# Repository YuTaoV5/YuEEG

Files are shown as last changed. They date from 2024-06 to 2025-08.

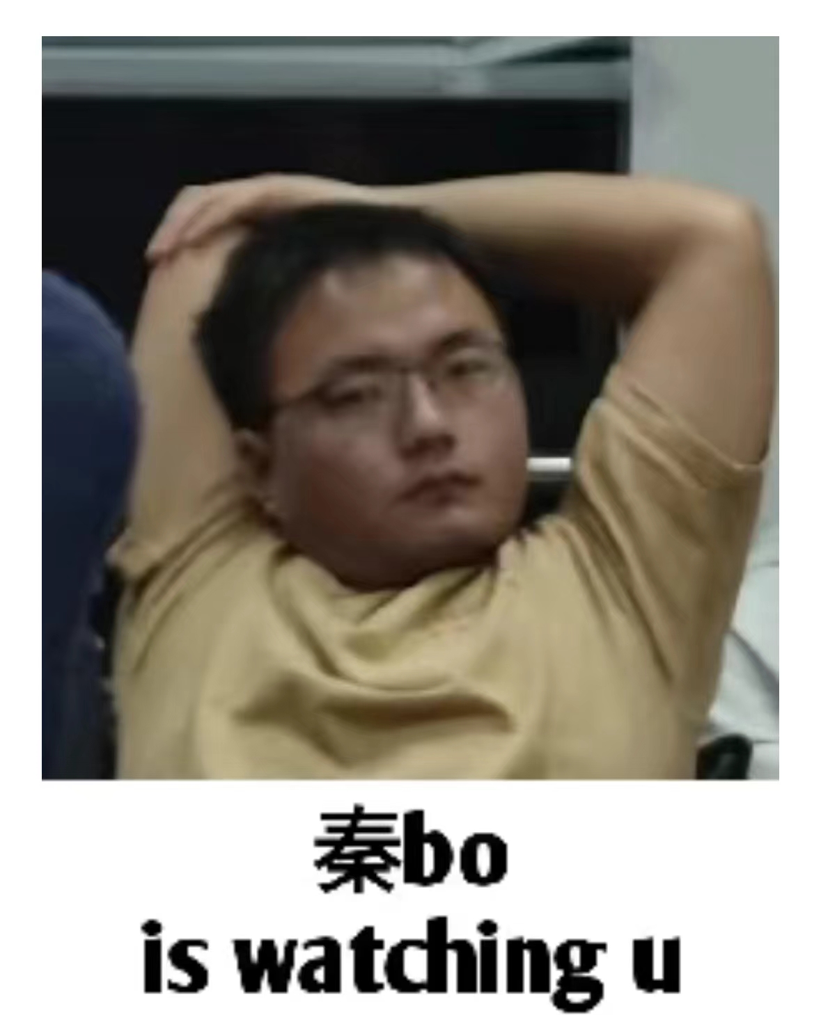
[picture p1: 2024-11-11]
Paradigm/usr/watch.jpg

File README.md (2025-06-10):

<div align="right">
    Image Description
</div>
<h1 align = "center">🌟YuEEG 8通道脑机接口设备🌟</h1>

<p align = "center">    





</p>

<p align = "center">    


</p>

## 概述 🧠🔌

本项目旨在利用 TI 的 ADS1299 芯片构建一个 8 通道的脑机接口（BCI）设备。项目涵盖硬件电路设计、芯片驱动开发以及数据接收和显示的上位机程序。

## 项目亮点

- **8 通道高分辨率 EEG 采集**，适合科研和创客项目。
- **定制 3D 打印脑电帽外壳**，设计舒适，便于精确放置电极。
- **兼容 Arduino 的驱动代码**，便于集成和控制，支持多种 EEG 应用和项目开发。

> [!CAUTION]
> 项目基于自定义的 MIT 协议，除本项目拥有者以外该项目不允许用来参加任何商业比赛。

> [!CAUTION]
> 【注意】请勿焊接TPS模块，直接使用USB供电，原因如下：
> ESP的Vbus引脚直连USB电源，并没有引脚二极管处理供电冲突所以请不要同时使用两种供电

> [!NOTE] 更新日志 2025/6/10
> 更新波形显示界面`FIFO_Plot.py`,添加去基线等滤波功能。修改部分驱动寄存器配置。

> [!NOTE] 更新日志 2024/12/7
> 项目已更新【SSVEP 范式】，后续还会添加APP以及网页波形显示，建议 Star 或者Fork后，作者会添加更多内容。

## 目录 📁

1. [项目背景](#项目背景)
2. [硬件设计](#硬件设计)
3. [软件开发](#软件开发)
4. [上位机程序](#上位机程序)
5. [使用指南](#使用指南)
6. [项目结构](#项目结构)
7. [贡献](#贡献)
8. [许可](#许可)

## 项目背景 📝

脑机接口（Brain-Computer Interface, BCI）是一种直接连接大脑和外部设备的系统，用于读取大脑活动信号并将其转换为机器指令。本项目使用 ADS1299 芯片，该芯片具有高分辨率和低噪声特性，非常适合 EEG（脑电图）信号的采集。

## 硬件设计 🔧

### 主要组件：

- **ADS1299 芯片**：用于 EEG 信号采集。
- **模拟前端电路**：包括滤波和放大电路。
- **电源管理模块**：提供稳定的电源供应。
- **数据传输接口**：用于与上位机通信。

### 电路设计图：

> 嘉立创链接：[https://oshwhub.com/protodrive000/1299_pro](https://oshwhub.com/protodrive000/1299_pro)
> 访问密码：yutaov5

| 正面 | 反面 |
| --- | --- |
|  |  |

### 外壳模型设计图：

> 3D 外壳文件：https://a360.co/3AnxQdK
> 访问密码：yutaov5

| 单外壳 | 外壳+脑电帽 | 仰视图 |
| --- | --- | --- |
|  |  |  |

## 上位机程序 📊

> 目前仅提供串口通讯的 plot_only.py 界面程序

### 功能：

- **数据接收**：通过串口接收来自硬件设备的数据。
- **数据展示**：实时显示 EEG 信号。
- **数据存储**：保存数据以便后续分析。

### 使用技术：

- **编程语言**：Python
- **图形库**：pyqt + fluent

### 界面截图：

| 正常采集模式 | 测试信号模式 |
| --- | --- |
|  |  |

## 范式程序
### 功能：

- **拼音输入**：通过C++编写的动态链接库。
- **联想拼写**：隐马尔可夫链模型。
- **分类算法**：FBCCA算法
- **支持多语言**：NLTK模型。

|配置界面|运行界面|
|-|-|
|||

>运行 ssvep_paradigm.py

## 使用指南 📚

### 硬件连接：

1. 本项目支持两种供电模式：
   - USB 接入 XiaoESP32S3 直接供电使用，同时串口发送数据
   - 背面焊接 TPS63070 锂电池转 5V 模块，然后电源接口接入 3.7V 锂电池即可
1. 将 EEG 电极正确连接到被测试者。
2. 使用 USB 线连接设备和电脑。
3. 硬件上支持BMM150以及Makerbase的MKS-142健康监测模块

### 引脚连接

```c++
// 定义引脚
#define CS_PIN    A3
#define SCLK_PIN  SCK
#define MOSI_PIN  MOSI
#define MISO_PIN  MISO
#define DRDY_PIN  A0
#define START_PIN A2
#define RESET_PIN A1
```

### 硬件设置

驱动代码是为支持 ESP32 的 Arduino IDE 编写的，代码通过 SPI 与 ADS1299 进行数据采集。

### 先决条件

- **Arduino IDE**：从[Arduino 官方网站](https://www.arduino.cc/en/software)下载最新版本。
- **ESP32 开发板包**：在 Arduino IDE 中通过开发板管理器添加 ESP32 开发板支持。

### 加载代码：

打开 Arduino IDE，选择 `文件` > `打开` 并选择 `ino 文件`。
在 `工具` > `开发板` 下选择你的 ESP32 开发板。
在 `工具` > `端口` 下设置正确的 COM 端口。

### 上传代码：

> 如果是第一次下载，上电前按住 boot 再上电后松开，然后正常下载

编译并将代码上传到 ESP32 开发板。

### 上位机代码使用方法

上传完成后，ESP32 开发板将开始与 ADS1299 芯片进行通信，并将 EEG 数据输出到串口监视器。

- 模式切换：使用以下串口命令或者左下方按钮切换不同模式：
  - 1：连续读取模式
  - 3：自检模式

> 示例用法
> 上传完成后，在 Arduino IDE 中打开串口监视器，波特率设为 115200。你将看到来自每个通道的实时 EEG 数据。

```C
// 数据格式如下
Channel 1: 0.123456, Channel 2: 0.654321, ..., Channel 8: 0.345678
```

### 上位机安装步骤

1. **克隆此仓库**：
   ```bash
   git clone https://github.com/YuTaoV5/YuEEG.git
   cd YuEEG
   ```
1. 安装所需库：
   ```bash
   pip install pyserial pyqt5
   pip install pyqtgraph PyQt-Fluent-Widgets
   pip install scikit-learn
   ```
1. 软件运行：
   ```bash
   python plot_only.py
   ```

## 贡献指南

欢迎社区贡献！请随时提交问题、功能请求或拉取请求。

## 未来改进

- 增加对不同微控制器的支持。
- 扩展脑电帽设计，以便调整电极位置。

## 致谢

特别感谢德州仪器提供 ADS1299 芯片，并感谢开源社区的启发与支持。

## 项目结构 🗂️

```
├── hardware
│   ├── schematics
│   └── pcb
├── firmware
│   └── ads1299_driver.ino
├── software
│   └── bci_gui.py
└── README.md
```

## 软件开发 💻

### 芯片驱动：

- **SPI 通信**：实现与 ADS1299 的 SPI 通信。
- **数据读取**：从芯片读取 EEG 数据。
- **数据处理**：初步处理和滤波。

### 引脚定义

| 引脚名称 | 描述 |
| --- | --- |
| CS_PIN | 片选引脚，低电平有效 |
| SCLK_PIN | SPI 时钟引脚 |
| MOSI_PIN | SPI 主设备输出从设备输入引脚 |
| MISO_PIN | SPI 主设备输入从设备输出引脚 |
| DRDY_PIN | 数据就绪引脚，低电平表示数据可读 |
| CLKSEL_PIN | 时钟选择引脚 |
| START_PIN  | 启动转换引脚 |
| RESET_PIN  | 重置引脚 |
| PWDN_PIN | 省电模式引脚 |

### 命令定义

| 命令 | 描述 |
| --- | --- |
| WAKEUP  | 唤醒芯片 |
| STANDBY | 进入待机模式 |
| RESET | 重置芯片 |
| START | 开始数据转换 |
| STOP | 停止数据转换 |
| RDATAC  | 连续读取数据 |
| SDATAC  | 停止连续读取数据 |
| RDATA | 读取数据 |
| RREG | 读取寄存器 |
| WREG | 写寄存器 |

### 定时器中断

代码中使用 ESP32 的定时器来定时读取数据和导联检测状态：

- `onDataTimer`: 检查数据是否就绪，如果就绪则设置标志位`startRead`。
- `onImpedanceTimer`: 读取导联检测状态。

### 初始化

在`setup`函数中：

- 初始化串口通信。
- 初始化引脚模式。
- 初始化 SPI 通信参数。
- 调用`initADS1299`函数初始化 ADS1299。
- 获取并打印设备 ID。
- 配置 ESP32 的定时器用于数据读取和导联检测。

### 主循环

在`loop`函数中：

- 检查串口是否有数据输入，用于切换连续读取模式和导联检测模式。
- 如果`startRead`标志位被设置，调用`readData`函数读取数据。

### 启动连续读取模式

`startContinuousReadMode`函数：

- 设置必要的标志位。
- 重置并初始化 ADS1299 的寄存器。
- 启动连续数据读取模式。
- 启动数据读取定时器，停止导联检测定时器。

### 启动导联检测模式

`startLeadOffDetectionMode`函数：

- 设置必要的标志位。
- 重置并初始化 ADS1299 的寄存器用于导联检测。
- 启动导联检测定时器，停止数据读取定时器。

### ADS1299 初始化

`initADS1299`函数：

- 启动 ADS1299 的时序。
- 重置芯片。
- 停止连续数据读取模式。
- 配置必要的寄存器。

### 读取导联检测状态

`readLeadOffStatus`函数：

- 读取`LOFF_STATP`和`LOFF_STATN`寄存器。
- 打印导联检测状态。

### 读取数据

`readData`函数：

- 从 ADS1299 读取数据。
- 将数据转换为电压并打印。

### 寄存器读写

包含`writeRegister`和`readRegister`函数，用于向 ADS1299 写入和读取寄存器。

### 数据转换

`convertData`函数：

- 将读取的字节数据转换为电压值。

这个代码框架基本涵盖了 ADS1299 的初始化、数据读取、导联检测等主要功能。在实际应用中，可能需要根据具体需求调整寄存器配置和定时器的时间间隔。确保 ADS1299 手册中的寄存器配置正确无误，以实现所需的功能。

### REF 和偏置电压（BIAS）的工作原理及电路连接

#### 1. 参考电极（REF）

参考电极是所有测量电极电位的基准点。它的作用是提供一个稳定的参考电压，以确保各个测量电极的电位能够被正确地采集。ADS1299 提供了灵活的配置选项，可以将任意电极设置为参考电极。

#### 2. 偏置电压（BIAS）

偏置电压用于提供共模电压稳定性和干扰抑制。在 EEG 测量中，人体容易受到共模干扰，如电源线频率的干扰（50/60Hz）。偏置电压通过向病人施加一个控制的电压，帮助将测量电极的共模电压保持在 ADS1299 输入范围内。ADS1299 的偏置放大器（BIAS amplifier）提供了一个内部的反馈回路，用于减少共模干扰。

#### 3. SRB 引脚

SRB（Signal Reference Buffer）引脚在 ADS1299 中用于信号参考电极的配置。

- **SRB1**：当 SRB1 引脚用于参考时，所有通道的负输入可以连接到 SRB1。设置`MISC1`寄存器的 SRB1 位可以实现这种配置。
- **SRB2**：SRB2 引脚可以选择单独的电极作为参考电极，并通过设置`CHnSET`寄存器的 SRB2 位，将该电极的电位作为其他通道的参考。

## 贡献 🤝

欢迎大家对本项目进行贡献！请提交 pull request 或创建 issue 以报告问题。

## 许可 📜

本项目采用基于 MIT 的许可。

```
MIT License with Restrictions

Copyright (c) [2024] [ZhangYutao]

Permission is hereby granted, free of charge, to any person obtaining a copy
of this software and associated documentation files (the "Software"), to deal
in the Software without restriction, including without limitation the rights
to use, copy, modify, merge, publish, distribute, sublicense, and/or sell
copies of the Software, and to permit persons to whom the Software is
furnished to do so, subject to the following conditions:

The above copyright notice and this permission notice shall be included in all
copies or substantial portions of the Software.

THE SOFTWARE IS PROVIDED "AS IS", WITHOUT WARRANTY OF ANY KIND, EXPRESS OR
IMPLIED, INCLUDING BUT NOT LIMITED TO THE WARRANTIES OF MERCHANTABILITY,
FITNESS FOR A PARTICULAR PURPOSE AND NONINFRINGEMENT. IN NO EVENT SHALL THE
AUTHORS OR COPYRIGHT HOLDERS BE LIABLE FOR ANY CLAIM, DAMAGES OR OTHER
LIABILITY, WHETHER IN AN ACTION OF CONTRACT, TORT OR OTHERWISE, ARISING FROM,
OUT OF OR IN CONNECTION WITH THE SOFTWARE OR THE USE OR OTHER DEALINGS IN THE
SOFTWARE.

Additional Restrictions:
The Software may not be used to participate in any commercial competitions or contests without the explicit permission of the copyright holder.
```

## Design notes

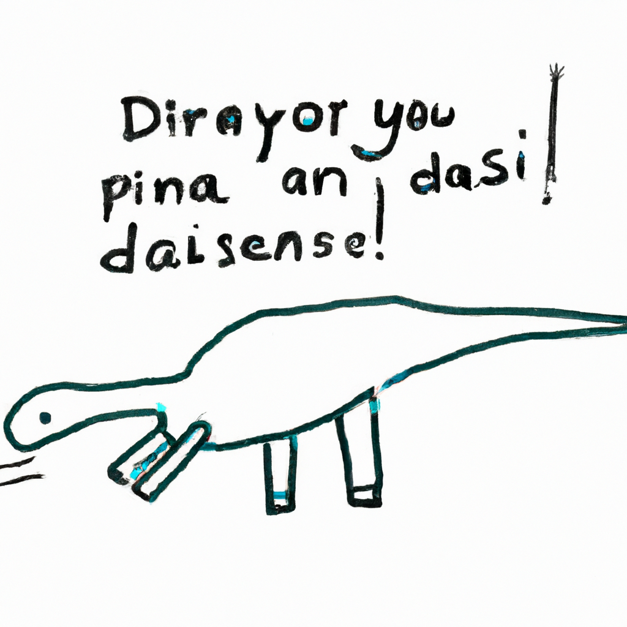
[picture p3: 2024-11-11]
Paradigm/usr/imgSave.png

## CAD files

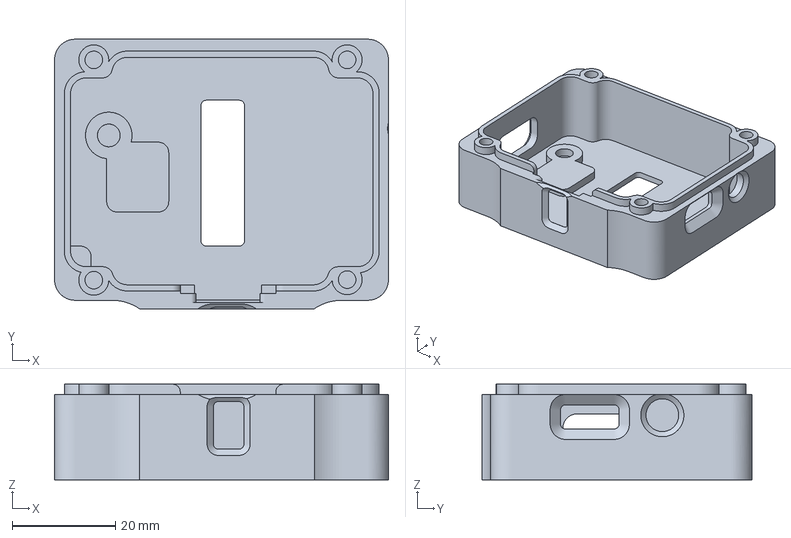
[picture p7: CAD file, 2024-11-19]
Model/外壳.3mf
64.6 x 52.1 x 18.5 mm

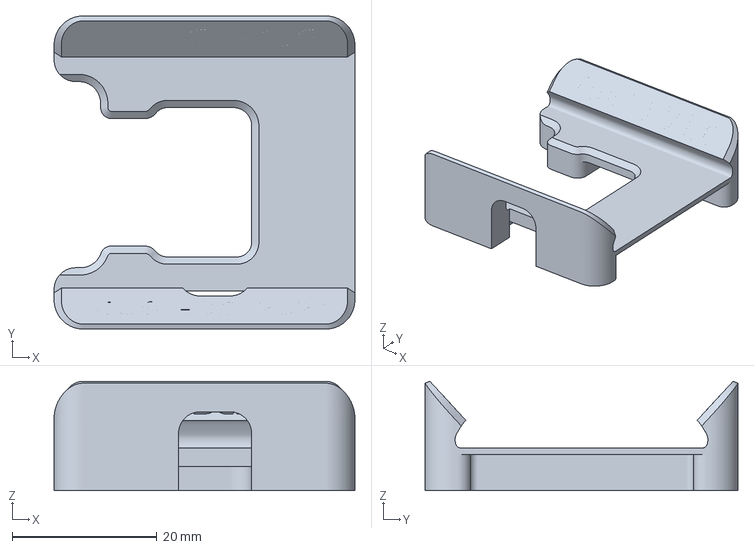
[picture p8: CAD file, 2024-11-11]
Model/挡板.3mf
41.6 x 43.3 x 15.1 mm

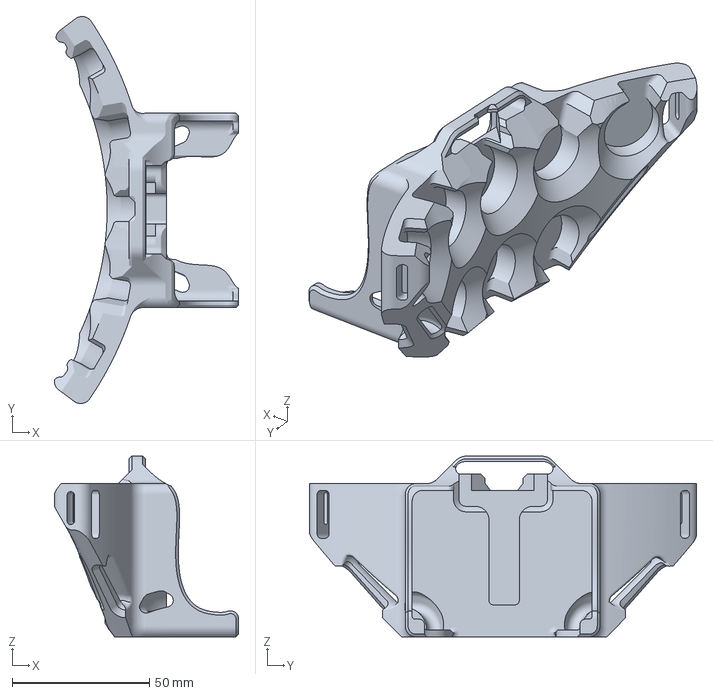
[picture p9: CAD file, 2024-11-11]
Model/脑电帽.3mf
67.3 x 141.2 x 66.0 mm

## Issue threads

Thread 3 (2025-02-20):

关于串口一直没有获得正确信号的问题

doubtfire009, 2025-02-20:
您好，感谢开源！我在嘉立创上打印了您的板子，在学习和测试，我自己焊接的Seeed Studio ESP32S3，但是我用手或者验电头触碰连接器的端口的时候，在串口一直没有获得正确的信号，始终是0。Seeed Studio ESP32S3应该是没有问题的，basic的blink示例代码是正常的。想请问下应该怎么调试呢？感激不尽！

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

YuTaoV5, 2025-02-20:
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
请参考这个，检测背部ADS1299内部基准电压

YuTaoV5, 2025-02-20:
一般来说烧入程序后，就直接有数据出来

doubtfire009, 2025-02-20:
感谢指点，我测试了一下电压，具体为：
Avss = -2.49
AVDD = 2.5

Vcap1 = -1.27
Vcap2 = 0
Vcap3 = 4.42
Vcap = -0.24

整体看起来也正常，我用万用表测试了通路，从通道1的干电极位置一直到INP1都是通的，但是DOUT没有测出电压，显示为0. 我猜测是不是芯片的设置有问题，没有生成数据。

我烧写的程序就是 ads1299_driver.ino。

您在开发的时候遇到过这种问题吗？

YuTaoV5, 2025-02-20:
尝试下载最新的ino文件试试？我没有遇到过这种情况
---- 回复的原邮件 ----
***@***.***>发送日期2025年02月20日 22:05 ***@***.***> ***@***.***>,
***@***.***>主题Re: [YuTaoV5/YuEEG] 关于串口一直没有获得正确信号的问题 (Issue #3)
感谢指点，我测试了一下电压，具体为：
Avss = -2.49
AVDD = 2.5
Vcap1 = -1.27
Vcap2 = 0
Vcap3 = 4.42
Vcap = -0.24
整体看起来也正常，我用万用表测试了通路，从通道1的干电极位置一直到INP1都是通的，但是DOUT没有测出电压，显示为0. 我猜测是不是芯片的设置有问题，没有生成数据。
我烧写的程序就是 ads1299_driver.ino。
您在开发的时候遇到过这种问题吗？
—
Reply to this email directly, view it on GitHub, or unsubscribe.
You are receiving this because you commented.Message ID: ***@***.***>
doubtfire009 left a comment (YuTaoV5/YuEEG#3)
感谢指点，我测试了一下电压，具体为：
Avss = -2.49
AVDD = 2.5
Vcap1 = -1.27
Vcap2 = 0
Vcap3 = 4.42
Vcap = -0.24
整体看起来也正常，我用万用表测试了通路，从通道1的干电极位置一直到INP1都是通的，但是DOUT没有测出电压，显示为0. 我猜测是不是芯片的设置有问题，没有生成数据。
我烧写的程序就是 ads1299_driver.ino。
您在开发的时候遇到过这种问题吗？
—
Reply to this email directly, view it on GitHub, or unsubscribe.
You are receiving this because you commented.Message ID: ***@***.***>

doubtfire009, 2025-02-21:
这周末，您是否在华理？能否我们见面聊一下，有偿请您指教？我邮箱756241126@qq.com，如果可以话请邮件联系我，感谢！

YuTaoV5, 2025-02-22:
XIAO背面raw是电池电源接入
不用电池就不必焊接,如果有5VUSB供电的话，RAW只涉及到DCDC3.3V的供电,xiao本身的3.3V可能带负载能力不强，请您留心

cjy4979, 2025-02-25:
您好，我这边调试也是始终输出全0，请问有可能是哪里出问题了

doubtfire009, 2025-02-25:
> 您好，我这边调试也是始终输出全0，请问有可能是哪里出问题了

有没有测试过对串口发送3，换成测试模式；再对串口发送1，换成正常传输数据模式？

YuTaoV5, 2025-02-25:
请使用最新更新的ino文件试试，我检查了一下，是上次提交代码有些bug，目前通道一是status, 2~9是脑电波形，后续我会用双缓冲
优化一下plot_only.py,目前绘图逻辑有点卡

cjy4979, 2025-02-25:
> > 您好，我这边调试也是始终输出全0，请问有可能是哪里出问题了
>
> 有没有测试过对串口发送3，换成测试模式；再对串口发送1，换成正常传输数据模式？

感谢，有效

doubtfire009, 2025-02-25:
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

切换有效对吗？有没有试过在发送1的时候输出的信号是什么

doubtfire009, 2025-02-25:
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如果使用

#define CONFIG_1 0xD5  // 9.6.1.2 对应Multiple readback mode，fMOD / 2048 (500 SPS) 采样率500个每秒
#define CONFIG_2 0xD0  //9.6.1.3 CONFIG2:
#define CONFIG_3 0xE0   // 9.6.1.4 CONFIG3:

上面3个配置还是输出一直为4.5.需要再研究下

cjy4979, 2025-02-27:
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

不用输入3再输入1，直接发1就可以。然后值和您差不多，第一个通道是一个特别大的数，剩下的一开始飘4.5，但是所有通道触摸电极均有效，我这边暂时正常，就是波形不好看

doubtfire009, 2025-02-27:
感谢！我去把所有电极焊好再试试。我之前是直接手指触摸接线口，没有焊电极

---原始邮件---
发件人: ***@***.***&gt;
发送时间: 2025年2月27日(周四) 晚上10:33
收件人: ***@***.***&gt;;
抄送: ***@***.******@***.***&gt;;
主题: Re: [YuTaoV5/YuEEG] 关于串口一直没有获得正确信号的问题 (Issue #3)

image.png (view on web)

如果使用

#define CONFIG_1 0xD5 // 9.6.1.2 对应Multiple readback mode，fMOD / 2048 (500 SPS) 采样率500个每秒 #define CONFIG_2 0xD0 //9.6.1.3 CONFIG2: #define CONFIG_3 0xE0 // 9.6.1.4 CONFIG3:

上面有几个通道输出还是一直为4.5.需要再研究下

不用输入3再输入1，直接发1就可以。然后值和您差不多，第一个通道是一个特别大的数，剩下的一开始飘4.5，但是所有通道触摸电极均有效，我这边暂时正常，就是波形不好看

—
Reply to this email directly, view it on GitHub, or unsubscribe.
You are receiving this because you authored the thread.Message ID: ***@***.***&gt;
  cjy4979 left a comment (YuTaoV5/YuEEG#3)

image.png (view on web)

如果使用

#define CONFIG_1 0xD5 // 9.6.1.2 对应Multiple readback mode，fMOD / 2048 (500 SPS) 采样率500个每秒 #define CONFIG_2 0xD0 //9.6.1.3 CONFIG2: #define CONFIG_3 0xE0 // 9.6.1.4 CONFIG3:

上面有几个通道输出还是一直为4.5.需要再研究下

不用输入3再输入1，直接发1就可以。然后值和您差不多，第一个通道是一个特别大的数，剩下的一开始飘4.5，但是所有通道触摸电极均有效，我这边暂时正常，就是波形不好看

—
Reply to this email directly, view it on GitHub, or unsubscribe.
You are receiving this because you authored the thread.Message ID: ***@***.***&gt;

Evan2you, 2025-03-01:
我遇到了相同的问题，在第一次尝试的时候，刚烧录程序然后上电选择1是没问题的，然后拔下电源，再上电模式1也是全变为了4.5

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

Evan2you, 2025-03-01:
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
啥也没改，用手随便碰了碰输入，又正常了，神奇

Evan2you, 2025-03-01:
用湿电极试了试，触摸单个电极或者许多电极变化不明显，要过大概一分钟左右波形就出现大幅度波动，不知道是不是延时，而且模式1用了一段时间也会有通道变为4.5的情况，在qt上位机中，三个通道切换不灵敏

doubtfire009, 2025-03-02:
> 用湿电极试了试，触摸单个电极或者许多电极变化不明显，要过大概一分钟左右波形就出现大幅度波动，不知道是不是延时，而且模式1用了一段时间也会有通道变为4.5的情况，在qt上位机中，三个通道切换不灵敏

我也出现了这种情况，你有没有试试使用电池和Seed Studio ESP32对接？电压稳定一些可能会好，我查了有可能是电压不稳定的原因

doubtfire009, 2025-03-03:
> 用湿电极试了试，触摸单个电极或者许多电极变化不明显，要过大概一分钟左右波形就出现大幅度波动，不知道是不是延时，而且模式1用了一段时间也会有通道变为4.5的情况，在qt上位机中，三个通道切换不灵敏

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

破案了，必须使用3.7伏的电池，效果才会好，能解决你说的不灵敏和波动。带电池的板子刚插上usb，会有红灯闪烁，需要过一阵子才能正常。没信号的时候输出4.5.，是正常的，这个时候输出的是内部参考电压；有信号的时候会有变化。

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

doubtfire009, 2025-03-03:
> XIAO背面raw是电池电源接入 不用电池就不必焊接,如果有5VUSB供电的话，RAW只涉及到DCDC3.3V的供电,xiao本身的3.3V可能带负载能力不强，请您留心

说的很对！我接上了电池，效果好多了。感谢指点！

Evan2you, 2025-03-03:
感谢，我试一下！

binghuoqishi, 2025-03-03:
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我才开始做这个项目，发现一半通道数值都不太正常，以为150的芯片给我焊废了，看来都这样，我会继续关注的

binghuoqishi, 2025-03-03:
我的芯片在自检模式下只有四个通道输出方波

doubtfire009, 2025-03-03:
那要查一下，理论上测试状态全部都应该有值。是不是电路有问题

---原始邮件---
发件人: ***@***.***&gt;
发送时间: 2025年3月3日(周一) 晚上10:27
收件人: ***@***.***&gt;;
抄送: ***@***.******@***.***&gt;;
主题: Re: [YuTaoV5/YuEEG] 关于串口一直没有获得正确信号的问题 (Issue #3)

我的芯片在自检模式下只有四个通道输出方波

—
Reply to this email directly, view it on GitHub, or unsubscribe.
You are receiving this because you authored the thread.Message ID: ***@***.***&gt;
  binghuoqishi left a comment (YuTaoV5/YuEEG#3)

我的芯片在自检模式下只有四个通道输出方波

—
Reply to this email directly, view it on GitHub, or unsubscribe.
You are receiving this because you authored the thread.Message ID: ***@***.***&gt;

doubtfire009, 2025-03-05:
大家注意了，我这边陷入了一个巨坑，损失惨重，跟大家说出来，大家引起警觉。

我因为手抖，而且只有电烙铁和电风筒，所以只能这样焊接Xiao ESP32S3和电池，

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

用排针插入之后焊接引脚，以及使用细导线和raw的引脚相连。

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

但是我看到UP主是直接贴着板子焊接的。

我这种方式，在刚上电的时候效果不错，一切正常。

但是！！！

我让他连续跑了20分钟之后，XIAO ESP32S3开始闪烁红灯

<!-- Failed to upload "video.mp4" -->

然后COM口就找不到了。

我尝试了好多方法：

https://forum.seeedstudio.com/t/seeedstudio-esp32s3-sense/274075

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

只对1个器件管用，其他3个器件都没用，还是一直闪烁，并且发热烫手。
又查了下，看起来是稳压器烧了：
https://forum.seeedstudio.com/t/short-circuit-between-3v3-and-gnd-on-xiao-esp32-s3/281088

同时测量电池电压，没有接线的时候，电池电压是3.0v；接线之后，发现Vout和GND是短路状态。

于是两手准备，下单买了加热焊台，预备彻底提升焊接的水平，全部贴板子焊接；
另外，花了1800元让嘉立创给我连板子带Xiao ESP32S3一起焊接，再测试看看效果。后续我再更新。

YuTaoV5, 2025-03-05:
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

> [!IMPORTANT]【注意】请勿焊接TPS模块，直接使用USB供电，原因如下： ESP的Vbus引脚直连USB电源，并没有引脚二极管处理> 供电冲突所以请不要同时使用两种供电，会直接烧坏XIAO-ESP, 这点我在项目已经标注了，最好就是只用USB供电，或者自行添加稳压二极管

YuTaoV5, 2025-03-05:
究其原因还是XIAO的供电以及锂电池管理屎一样，有机会可能的话可以换微雪那个ESP32s3小板子

doubtfire009, 2025-03-05:
感谢，我晚上拿旧板子试试看。旧板子已经快烧糊了哈哈

---原始邮件---
发件人: ***@***.***&gt;
发送时间: 2025年3月5日(周三) 下午2:45
收件人: ***@***.***&gt;;
抄送: ***@***.******@***.***&gt;;
主题: Re: [YuTaoV5/YuEEG] 关于串口一直没有获得正确信号的问题 (Issue #3)

板子底下raw不是一定要焊接的，他在电路图中只有3.3V稳压的输入作用，在板子右上方单接一个锂电池作为raw引脚输入就好

—
Reply to this email directly, view it on GitHub, or unsubscribe.
You are receiving this because you authored the thread.Message ID: ***@***.***&gt;
  YuTaoV5 left a comment (YuTaoV5/YuEEG#3)

板子底下raw不是一定要焊接的，他在电路图中只有3.3V稳压的输入作用，在板子右上方单接一个锂电池作为raw引脚输入就好

—
Reply to this email directly, view it on GitHub, or unsubscribe.
You are receiving this because you authored the thread.Message ID: ***@***.***&gt;

YuTaoV5, 2025-03-05:
切勿花大价钱贴片，真的没必要，可以私我邮箱联系我寄送原材料，手焊就半小时事情

binghuoqishi, 2025-03-05:
嘉立创贴片确实没必要，我开了钢网，之后配合加热台尝试第二板，焊太多次怕把ads1299焊坏了

doubtfire009, 2025-03-05:
> 切勿花大价钱贴片，真的没必要，可以私我邮箱联系我寄送原材料，手焊就半小时事情

感谢感谢！您的时间也宝贵，暂时不麻烦您，我一方面下单买了加热焊台，第二是这次已经让他出片了，我这次交点学费，把坑多踩一踩，下次就明白了。我是之后要自己设计一版电路图，加上保护二极管、换成别的器件，到那时候再开钢网手动焊接。您的忠告我很感激，下次不找他们了。他们的加工费要800多。

有空在杭州或者上海面基聊聊~

doubtfire009, 2025-03-05:
> 嘉立创贴片确实没必要，我开了钢网，之后配合加热台尝试第二板，焊太多次怕把ads1299焊坏了

感谢了！下次我也去开钢网，这次不了解，属于学习过程

doubtfire009, 2025-03-05:
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

一个50块钱，目前买了4个了，烧了3个哈哈哈。又买了3个寄给嘉立创，然后自己买了3个准备测试下他的TinyML

Evan2you, 2025-03-05:
请问在开关上方加一个3.7锂电供电解决电压不足问题，不用焊接TPS那个模块，然后xiaoESP32电源那也不用焊接对吗
doubtfire009 ***@***.***>于2025年3月5日 周三15:58写道：

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

ptrzs3, 2025-03-05:
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
这是我自己画的ESP32S3驱动ADS1299的板子，驱动程序用的博主的arduino程序，在模式1下的输出内容是这样的，目前是裸露电极，我不清楚目前的输出是否正常，希望各位能够指导一下

doubtfire009, 2025-03-05:
> 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
>
> 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 这是我自己画的ESP32S3驱动ADS1299的板子，驱动程序用的博主的arduino程序，在模式1下的输出内容是这样的，目前是裸露电极，我不清楚目前的输出是否正常，希望各位能够指导一下

一般是启动后过段时间，数据开始都生成4.5，这个时候扰动接口数据会出现变化，应该这个就算正常。ADS1299内部偏置电压是4.5，输出的电压都是在-4.5-4.5的范围

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

YuTaoV5, 2025-03-05:
我已上传最新修改ino以及显示上位机, 去试一试新的吧
【注意：opa的7脚应该连接avdd，这是几个月前改的，之前画的有问题少接了一个线，修改的话飞线一下也行

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

binghuoqishi, 2025-03-06:
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搞了一个下午，终于有正常的自检信号了，阵亡一颗ads1299，报废一块pcb，总结钢网对ads1299这种密集的引脚帮助不大，还有连锡要手动处理.

YuTaoV5, 2025-03-06:
请使用我昨天上传的新ino以及py程序看看效果
---- 回复的原邮件 ----
***@***.***>发送日期2025年3月6日 ***@***.***>***@***.***>,
***@***.***>主题Re: [YuTaoV5/YuEEG] 关于串口一直没有获得正确信号的问题 (Issue #3)
IMG_20250306_161152.jpg (view on web)搞了一个下午，终于有正常的自检信号了，阵亡一颗ads1299，报废一块pcb，总结钢网对ads1299这种密集的引脚帮助不大，还有连锡要手动处理.
—
Reply to this email directly, view it on GitHub, or unsubscribe.
You are receiving this because you commented.Message ID: ***@***.***>
binghuoqishi left a comment (YuTaoV5/YuEEG#3)
IMG_20250306_161152.jpg (view on web)搞了一个下午，终于有正常的自检信号了，阵亡一颗ads1299，报废一块pcb，总结钢网对ads1299这种密集的引脚帮助不大，还有连锡要手动处理.
—
Reply to this email directly, view it on GitHub, or unsubscribe.
You are receiving this because you commented.Message ID: ***@***.***>

doubtfire009, 2025-03-06:
https://github.com/user-attachments/assets/03b04182-6866-4a9f-a3a1-6f5e2b8cd84a

很奇怪，我这次买了焊台，自己焊接了Seeed Studio，blink程序正常，串口也能找到；但是连接了usb之后，一直闪烁红灯，

<!-- Failed to upload "image.png" -->

Serial.available() 一直为0，这个有可能是什么原因？

我自测

Avss = -2.49
AVDD = 2.5
Vcap1 = -1.27
Vcap2 = 0
Vcap3 = 4.42
Vcap = -0.24
vrefp=-2.28
vrefn=-2.48

这些貌似都正常。

Aknifejackzhmolong, 2025-03-25:
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

遇到了相同的问题，老哥你后来解决了吗

doubtfire009, 2025-03-25:
解决了，我调试出数据以后，新打了一块板子，直接接usb串口，不接电池，就正常了。使用up主最新版的驱动脚本

---原始邮件---
发件人: "Dejiao ***@***.***&gt;
发送时间: 2025年3月26日(周三) 凌晨0:49
收件人: ***@***.***&gt;;
抄送: ***@***.******@***.***&gt;;
主题: Re: [YuTaoV5/YuEEG] 关于串口一直没有获得正确信号的问题 (Issue #3)

查过了，是虚焊导致的。我先使用了一个新的seeed xiao esp32s3，连上usb，烧写程序获得结果跟这一样，我就基本确定是焊接不好导致的。我卸掉，重新用7排针焊接，这次就可以出数据了。下周嘉立创的新板子拿来，再测试一下对比数据看看

===============================================================================

video.1.mp4
 很奇怪，我这次买了焊台，自己焊接了Seeed Studio，blink程序正常，串口也能找到；但是连接了usb之后，一直闪烁红灯，

image.png (view on web)

Serial.available() 一直为0，这个有可能是什么原因？

我自测

Avss = -2.49 AVDD = 2.5 Vcap1 = -1.27 Vcap2 = 0 Vcap3 = 4.42 Vcap = -0.24 vrefp=-2.28 vrefn=-2.48

这些貌似都正常。

有谁遇到过类似的问题吗

遇到了相同的问题，老哥你后来解决了吗

—
Reply to this email directly, view it on GitHub, or unsubscribe.
You are receiving this because you authored the thread.Message ID: ***@***.***&gt;
  Aknifejackzhmolong left a comment (YuTaoV5/YuEEG#3)

查过了，是虚焊导致的。我先使用了一个新的seeed xiao esp32s3，连上usb，烧写程序获得结果跟这一样，我就基本确定是焊接不好导致的。我卸掉，重新用7排针焊接，这次就可以出数据了。下周嘉立创的新板子拿来，再测试一下对比数据看看

===============================================================================

video.1.mp4
 很奇怪，我这次买了焊台，自己焊接了Seeed Studio，blink程序正常，串口也能找到；但是连接了usb之后，一直闪烁红灯，

image.png (view on web)

Serial.available() 一直为0，这个有可能是什么原因？

我自测

Avss = -2.49 AVDD = 2.5 Vcap1 = -1.27 Vcap2 = 0 Vcap3 = 4.42 Vcap = -0.24 vrefp=-2.28 vrefn=-2.48

这些貌似都正常。

有谁遇到过类似的问题吗

遇到了相同的问题，老哥你后来解决了吗

—
Reply to this email directly, view it on GitHub, or unsubscribe.
You are receiving this because you authored the thread.Message ID: ***@***.***&gt;

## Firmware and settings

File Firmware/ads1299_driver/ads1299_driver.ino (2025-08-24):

#include <SPI.h>
#include "esp_timer.h"

// ================== 宏定义区 ==================
// ---------- 采样率配置 ----------
#define CONFIG1_REG  0x95   // 单片模式，500 SPS
#define CONFIG2_REG  0xC0   // 常规采样，无测试信号
#define CONFIG3_REG  0xEC   // 内部参考、BIAS 缓冲开启

// ---------- 通道配置 ----------
#define CHnSET_REG   0x60   // 增益 24x，普通电极输入
#define ENABLE_SRB1  0x20   // MISC1: 启用 SRB1
#define BIAS_SENSP   0xFF   // BIAS 正端全开
#define BIAS_SENSN   0xFF   // BIAS 负端全开

// ---------- 阻抗测量配置 ----------
#define LOFF_CONFIG   0x06  // 选择 6nA，FLEAD_OFF=10(31.2Hz)
#define LOFF_SENSP    0xFF  // 开启所有通道正端注入
#define LOFF_SENSN    0xFF  // 开启所有通道负端注入

// ---------- 模式选择 ----------
#define MODE_CONTINUOUS_READ   1
#define MODE_IMPEDANCE_MEASURE 2
#define MODE_SELF_TEST         3

// ================== 引脚定义 ==================
#define CS_PIN    A3
#define SCLK_PIN  SCK
#define MOSI_PIN  MOSI
#define MISO_PIN  MISO
#define DRDY_PIN  A0
#define START_PIN A2
#define RESET_PIN A1

// ================== 命令定义 ==================
#define WAKEUP  0x02
#define STANDBY 0x04
#define RESET   0x06
#define START   0x08
#define STOP    0x0A
#define RDATAC  0x10
#define SDATAC  0x11
#define RDATA   0x12
#define RREG    0x20
#define WREG    0x40

// ================== 全局变量 ==================
volatile bool dataReady = false; // DRDY 中断标志
int currentMode = MODE_CONTINUOUS_READ;
double channelDataBuffer[9]; // 0=STATUS，其余 8 个通道

// ================== 函数声明 ==================
void IRAM_ATTR onDRDYInterrupt();
void initADS1299();
void startContinuousReadMode();
void startImpedanceMeasurementMode();
void startSelfTestMode();
void readData();
void convertData(byte *data, double *channelData);
void sendCommand(byte cmd);
void writeRegister(byte reg, byte value);
byte readRegister(byte reg);
void getDeviceID();

// ================== setup ==================
void setup() {
  Serial.begin(115200);

  // 初始化引脚
  pinMode(CS_PIN, OUTPUT);
  pinMode(SCLK_PIN, OUTPUT);
  pinMode(MOSI_PIN, OUTPUT);
  pinMode(MISO_PIN, INPUT);
  pinMode(DRDY_PIN, INPUT);
  pinMode(START_PIN, OUTPUT);
  pinMode(RESET_PIN, OUTPUT);

  digitalWrite(CS_PIN, LOW);  // CS 默认拉高
  digitalWrite(START_PIN, LOW);
  digitalWrite(RESET_PIN, HIGH);
  delay(100);

  // 初始化 SPI
  SPI.begin(SCLK_PIN, MISO_PIN, MOSI_PIN, CS_PIN);
  SPI.beginTransaction(SPISettings(SPI_CLOCK_DIV8, MSBFIRST, SPI_MODE1));

  // 初始化 ADS1299
  initADS1299();
  getDeviceID();
  Serial.println("ADS1299 初始化完成");

  // 配置外部中断（DRDY 下降沿触发）
  attachInterrupt(digitalPinToInterrupt(DRDY_PIN), onDRDYInterrupt, FALLING);

  currentMode = MODE_CONTINUOUS_READ;
}

// ================== loop ==================
void loop() {
  // 串口命令切换模式
  if (Serial.available()) {
    char cmd = Serial.read();
    if (cmd == '1') {
      currentMode = MODE_CONTINUOUS_READ;
      startContinuousReadMode();
    } else if (cmd == '2') {
      currentMode = MODE_IMPEDANCE_MEASURE;
      startImpedanceMeasurementMode();
    } else if (cmd == '3') {
      currentMode = MODE_SELF_TEST;
      startSelfTestMode();
    }
  }

  // 有数据时读取
  if (dataReady) {
    dataReady = false;
    Serial.print("channel:");
    for (int i = 1; i <= 8; i++) {
      Serial.print(channelDataBuffer[i], 6); // V 输出
      if (i < 8) Serial.print(",");
    }
    Serial.println();
  }
}

// ================== 中断服务函数 ==================
void IRAM_ATTR onDRDYInterrupt() {
  readData(); // 读取数据 
}

// ================== 模式配置 ==================
void startContinuousReadMode() {
  sendCommand(RESET);
  delay(100);
  sendCommand(SDATAC);
  writeRegister(0x01, CONFIG1_REG);
  writeRegister(0x02, CONFIG2_REG);
  writeRegister(0x03, CONFIG3_REG);
  for (int i = 0x05; i <= 0x0C; i++) writeRegister(i, CHnSET_REG);
  writeRegister(0x0D, BIAS_SENSP);
  writeRegister(0x0E, BIAS_SENSN);
  writeRegister(0x15, ENABLE_SRB1);
  sendCommand(START);
  sendCommand(RDATAC);
}

void startImpedanceMeasurementMode() {
  sendCommand(RESET);
  delay(100);
  sendCommand(SDATAC);
  writeRegister(0x04, LOFF_CONFIG);
  writeRegister(0x0F, LOFF_SENSP);
  writeRegister(0x10, LOFF_SENSN);
  for (int i = 0x05; i <= 0x0C; i++) writeRegister(i, CHnSET_REG);
  sendCommand(START);
  sendCommand(RDATAC);
  Serial.println("阻抗测量模式已启用（注意需解调导联频率信号）");
}

void startSelfTestMode() {
  sendCommand(RESET);
  delay(100);
  sendCommand(SDATAC);
  writeRegister(0x01, 0x95); // 500SPS
  writeRegister(0x02, 0xD1); // 开启测试信号
  writeRegister(0x03, CONFIG3_REG);
  for (int i = 0x05; i <= 0x0C; i++) writeRegister(i, 0x65); // 测试信号输入
  sendCommand(START);
  sendCommand(RDATAC);
  Serial.println("自检模式已启用");
}

// ================== 初始化 ==================
void initADS1299() {
  sendCommand(RESET);
  delay(100);
  sendCommand(SDATAC);

  writeRegister(0x01, CONFIG1_REG);
  writeRegister(0x02, CONFIG2_REG);
  writeRegister(0x03, CONFIG3_REG);
  for (int i = 0x05; i <= 0x0C; i++) writeRegister(i, CHnSET_REG);
  writeRegister(0x0D, BIAS_SENSP);
  writeRegister(0x0E, BIAS_SENSN);
  writeRegister(0x15, ENABLE_SRB1);

  // 默认关闭导联检测
  writeRegister(0x04, 0x00);
  writeRegister(0x0F, 0x00);
  writeRegister(0x10, 0x00);

  sendCommand(START);
  sendCommand(RDATAC);
}

// ================== 数据读取 ==================
void readData() {
  byte data[27];
  digitalWrite(CS_PIN, LOW);
  for (int i = 0; i < 27; i++) data[i] = SPI.transfer(0x00);
  digitalWrite(CS_PIN, HIGH);
  convertData(data, channelDataBuffer);

  // 设置标志，表示数据已经准备好 
  dataReady = true;
}

void convertData(byte *data, double *channelData) {
  // 解析 STATUS
  long statusValue = ((long)data[0] << 16) | ((long)data[1] << 8) | data[2];
  channelData[0] = (double)statusValue;

  // 转换通道
  for (int i = 0; i < 8; i++) {
    long raw = ((long)data[3*i+3] << 16) | ((long)data[3*i+4] << 8) | data[3*i+5];
    if (raw & 0x800000) raw |= 0xFF000000; // 符号扩展
    double vPerLSB = 4.5 / (24.0 * 8388608.0); // 单位 V
    channelData[i+1] = (double)raw * vPerLSB;          // 输出电压 (V)
  }
}

// ================== 底层 SPI 操作 ==================
void sendCommand(byte cmd) {
  digitalWrite(CS_PIN, LOW);
  SPI.transfer(cmd);
  digitalWrite(CS_PIN, HIGH);
}

void writeRegister(byte reg, byte value) {
  digitalWrite(CS_PIN, LOW);
  SPI.transfer(WREG | reg);
  SPI.transfer(0x00);
  SPI.transfer(value);
  digitalWrite(CS_PIN, HIGH);
}

byte readRegister(byte reg) {
  digitalWrite(CS_PIN, LOW);
  SPI.transfer(RREG | reg);
  SPI.transfer(0x00);
  byte val = SPI.transfer(0x00);
  digitalWrite(CS_PIN, HIGH);
  return val;
}

void getDeviceID() {
  digitalWrite(CS_PIN, LOW);
  SPI.transfer(SDATAC);
  SPI.transfer(RREG | 0x00);
  SPI.transfer(0x00);
  byte id = SPI.transfer(0x00);
  digitalWrite(CS_PIN, HIGH);
  Serial.print("Device ID: 0b");
  Serial.println(id, BIN);
}

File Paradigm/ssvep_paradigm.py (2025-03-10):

# -*- coding: utf-8 -*-

'''库文件'''
import math
import random
import sys
import time
import datetime
import logging
from loguru import logger
from PyQt5.QtCore import *
from PyQt5.QtWidgets import *
from PyQt5.QtGui import *
import numpy as np
from pyqtgraph import PlotWidget, mkPen
from qfluentwidgets import *
from qfluentwidgets import FluentIcon as FIF
from collections import deque
from scipy.signal import iirnotch, lfilter, welch

logging.basicConfig(level=logging.INFO)  # logging.INFO
import re

'''辅助功能'''
from ui.ui import initUI
# from chat_ui import *
from src.FBCCA2 import fbcca_realtime
from src.tts import TTS
from Multi_Language import MultiLangAutoComplete, word_tokenize

import numpy as np
from collections import deque
from PyQt5 import QtWidgets, QtCore
import serial
import serial.tools.list_ports
from scipy.signal import butter, lfilter, lfilter_zi

# 配置参数
DATA_LENGTH = 20000  # 数据缓存长度
PLOT_LENGTH = 750  # 显示数据长度
FFT_LENGTH = 1000  # FFT分析长度
UPDATE_INTERVAL = 30  # 界面刷新间隔(ms)
SAMPLE_RATE = 500  # 采样率
FILTER_CUTOFF = 45  # 低通滤波截止频率
# 新增滤波器参数
NOTCH_FREQ = 50.0  # 陷波频率
QUALITY_FACTOR = 30  # 品质因数（决定带宽）

class SerialThread(QtCore.QThread):
    data_received = QtCore.pyqtSignal(str)

    def __init__(self, com_port):
        super().__init__()
        self.com_port = com_port
        self.serial_port = None
        self.running = False
        self.data_buffer = [[] for _ in range(9)]  # 动态数据池
        self.timestamps = []  # 时间戳记录
        self.write_index = 0
        self.max_data_length = 1_000_000  # 最大数据量限制

        # 初始化滤波器参数
        self.b_notch = [1] * 9  # 滤波器分子系数
        self.a_notch = [1] * 9  # 滤波器分母系数
        self.zi_notch = [np.zeros(2) for _ in range(9)]  # 滤波器状态

        # 设计50Hz陷波滤波器
        nyquist = 0.5 * SAMPLE_RATE
        freq = NOTCH_FREQ / nyquist
        self.b_notch, self.a_notch = iirnotch(freq, QUALITY_FACTOR)

        # 为每个通道初始化滤波器状态
        for i in range(9):
            self.zi_notch[i] = lfilter_zi(self.b_notch, self.a_notch)


    def run(self):
        self.running = True
        try:
            self.serial_port = serial.Serial(self.com_port, baudrate=115200, timeout=1)
            self.serial_port.write(b'1')  # 启动数据传输
            while self.running:
                if self.serial_port.in_waiting:
                    try:
                        raw_data = self.serial_port.readline().decode('utf-8', errors='ignore').strip()
                        self.data_received.emit(raw_data)
                        # 使用正则表达式验证数据格式
                        if re.match(r'^Channel:(-?\d+\.?\d*,){8}-?\d+\.?\d*$', raw_data):
                            values = list(map(float, raw_data.split('Channel:')[1].split(',')))
                            self._update_buffer(values)
                    except Exception as e:
                        print(f"Error processing data: {e}")
        finally:
            if self.serial_port and self.serial_port.is_open:
                self.serial_port.close()

    def _update_buffer(self, values):
        # 应用50Hz陷波滤波
        filtered_values = []
        for i in range(9):
            # 使用lfilter进行实时滤波处理
            filtered_value, self.zi_notch[i] = lfilter(
                self.b_notch,
                self.a_notch,
                [values[i]],
                zi=self.zi_notch[i]
            )
            filtered_values.append(filtered_value[0])

        # 将滤波后的数据存入缓冲区（替代原始数据）
        while len(self.timestamps) >= self.max_data_length:
            for ch in self.data_buffer:
                ch.pop(0)
            self.timestamps.pop(0)

        for i in range(9):
            self.data_buffer[i].append(filtered_values[i])
        self.timestamps.append(self.write_index)
        self.write_index += 1

    def get_plot_data(self, length=PLOT_LENGTH):
        valid_length = min(len(self.timestamps), length)
        start = max(0, len(self.timestamps) - valid_length)
        x_axis = np.arange(start, start + valid_length)
        data = [np.array(ch[start:start + valid_length]) for ch in self.data_buffer]
        return x_axis, np.array(data)

    def get_fft_data(self):
        return self.get_plot_data(FFT_LENGTH)

    def get_last_data(self, num):
        """获取最新的num个点数据，返回形状为(9, num)的ndarray"""
        data = []
        for ch in self.data_buffer:
            if len(ch) >= num:
                data.append(np.array(ch[-num:]))
            else:
                padding = np.full(num - len(ch), np.nan)
                data.append(np.concatenate([padding, ch]))
        return np.array(data)

    def stop(self):
        self.running = False
        self.wait(2000)

# Example usage:
# self.serial_thread = SerialThread(com_port)
# self.serial_thread.start()
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

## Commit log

2024-11-11 update readme, change gui
    [挡板.3mf, 脑电帽.3mf, 设备外壳.3mf]
2024-11-11 add paradigm
    [挡板.3mf, 脑电帽.3mf, 设备外壳.3mf]
2024-11-11 change 3mf files
    [挡板.3mf, 脑电帽.3mf]
2024-11-11 update model
    [外壳.3mf, 挡板.3mf, 设备外壳.3mf]
2024-11-19 change 外壳.3mf
    [外壳.3mf]
2025-08-24 normal update
    [EEG_log_20250824_184640.csv, EEG_log_20250824_184954.csv, EEG_log_20250824_185109.csv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]
2025-08-24 delate some log
    [EEG_log_20250824_184640.csv, EEG_log_20250824_184954.csv, EEG_log_20250824_185109.csv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]
2026-10-27 Compact Rev F into top-side mainboard and isolated charger daughterboard
